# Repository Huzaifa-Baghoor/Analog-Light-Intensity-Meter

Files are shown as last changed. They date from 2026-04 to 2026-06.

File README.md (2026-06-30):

# Analog Light Intensity Meter

I wanted to make some projects without microcontroller so I made this **light intensity meter** which indicates light in 10 distinct levels.
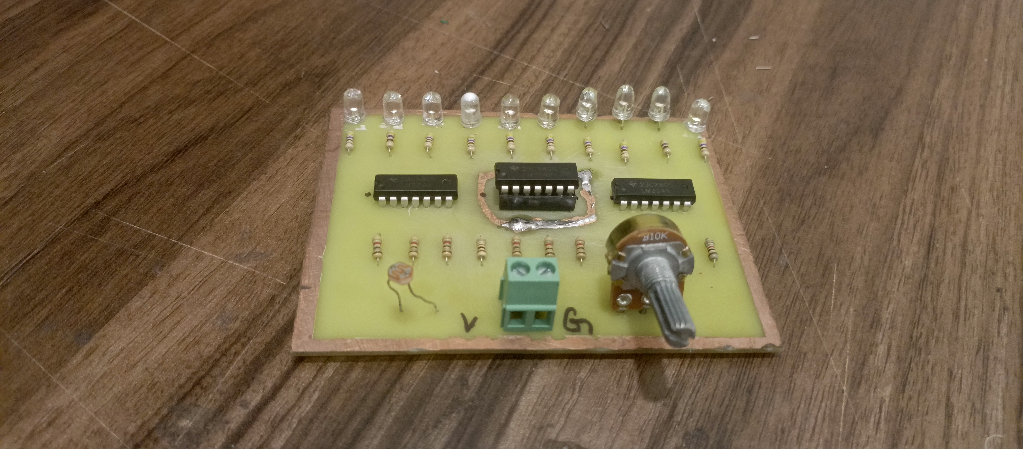
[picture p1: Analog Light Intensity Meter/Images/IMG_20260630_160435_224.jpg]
3D Model


## Working

The **LM324N IC** contains 4 OpAmps which are being used as Comparaters. They compare two voltages i.e. **reference voltage** and **signal voltage** and  if signal voltage is higher than reference voltage the output is on and all the LEDs till that level turn on.

## PCB and Connections

The Project is powered by a 9V source the thee +9V goes to the VCC of op Amps and top of the voltage divider bridge and top of the sensitivity control area the Gnd goes to the GND of op Amps and bottom of the voltage divider bridge and bottom of the sensitivity control area . The signal from the senstivity control area goes to the +ve of op amps and the 10 voltage levels are connected to -ve of 10 individual op Amps.

**The PCB isn't working but if you try to make it on breadboard using the same schematics then it works fine.**

|Schematics|Tracks|
| :---: | :---: |
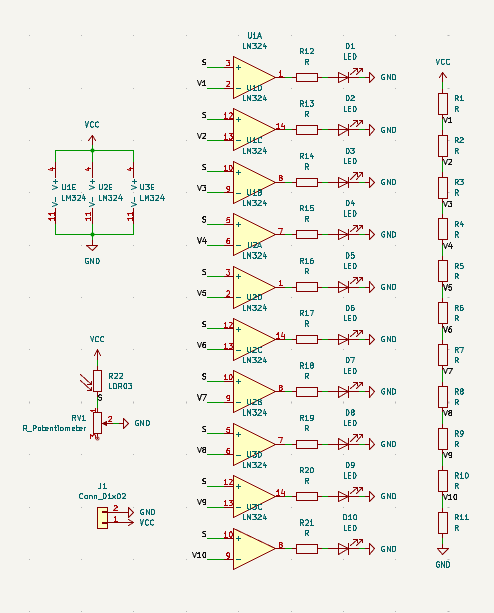
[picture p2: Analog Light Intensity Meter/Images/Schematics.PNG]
schemetics
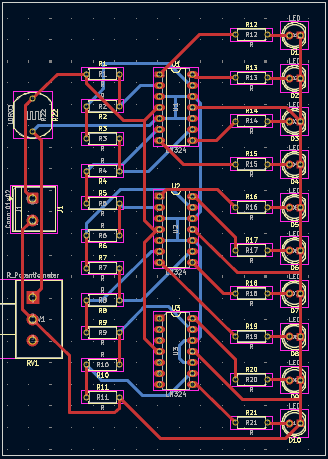
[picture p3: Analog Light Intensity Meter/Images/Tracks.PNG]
Tracks
|  |  |

## Bill of Materials (BOM)

| Name | Purpose | Quantity | Total Cost (USD) | Link | Distributor |
| :---: | :---: | :---: | :---: | :---: | :---: |
| LEDs | Indicator | 10 | 7 | [LED](https://www.aliexpress.com/item/1005003337390606.html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) | AliExpress |
| PCB | to assemble the project | 1 | 35 | [PCB](https://cart.jlcpcb.com/quote/gerberviewThree/?qs=edae4f3f128a488bbbc25f9c6c296d6c_1_0_1_0_0.html) | AliExpress
| IC Base | to solder ICs on PCB or Veroboard |  | 2 | [IC Base](https://www.aliexpress.com/item/32866483409.html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) | AliExpress |
| Potentiometer | Control Senstivity | 1 | 3 | [Potentiometer](https://www.aliexpress.com/item/1005007730415902.html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) | AliExpress |
| LDR | Detecting Light level | 1 | 3 | [LDR](https://www.aliexpress.com/item/1005010362917938.html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) | AliExpress |
| 1kΩ Resistor | For Voltage Divider Bridge | 11 | 2 | [1K Resistor](https://www.aliexpress.com/item/1005009177180559.html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) | AliExpress |
| 470Ω Resistor | for LEDs | 10 | 2 | [470R Resistor](https://www.aliexpress.com/item/1005009177180559.html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) | AliExpress |
| LM324N | Quad OpAmp ICs | 6 | 7 | [LM324N IC](https://www.aliexpress.com/item/1005008583669771.html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) | AliExpress |

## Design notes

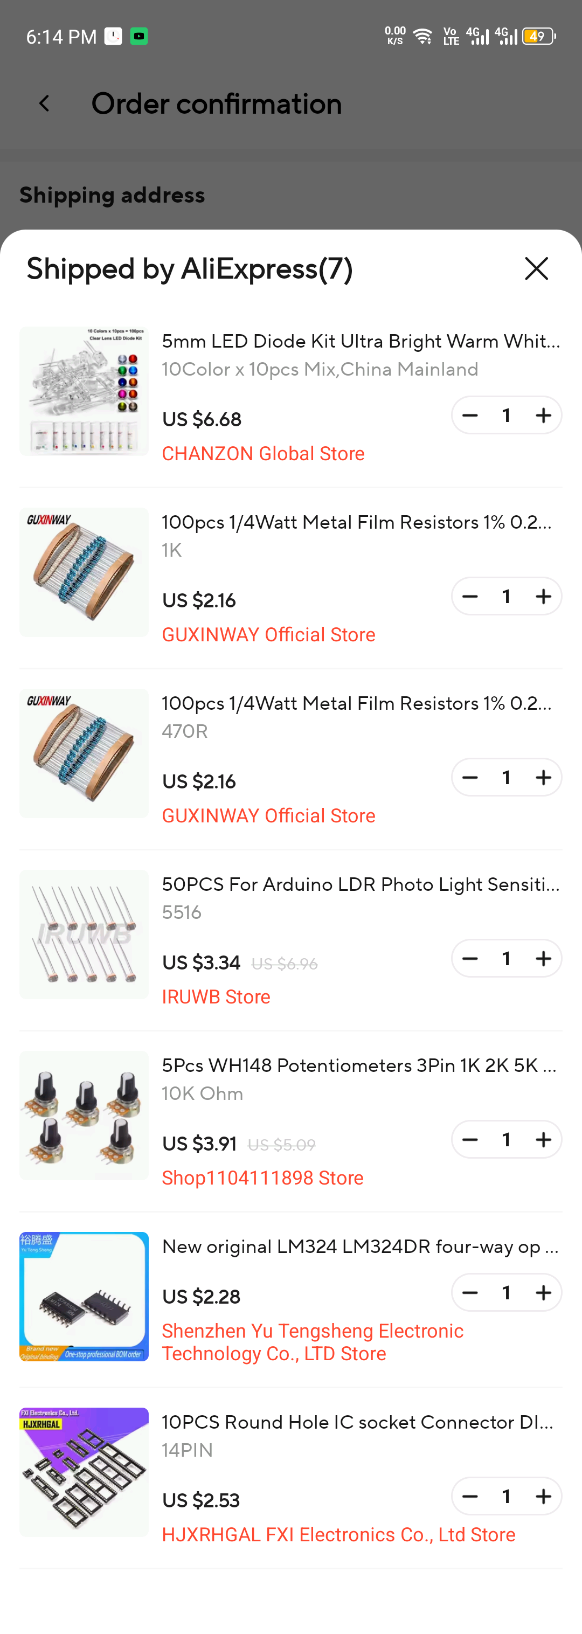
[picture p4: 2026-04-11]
Analog Light Intensity Meter/Images/Screenshot_20260411-181429.png

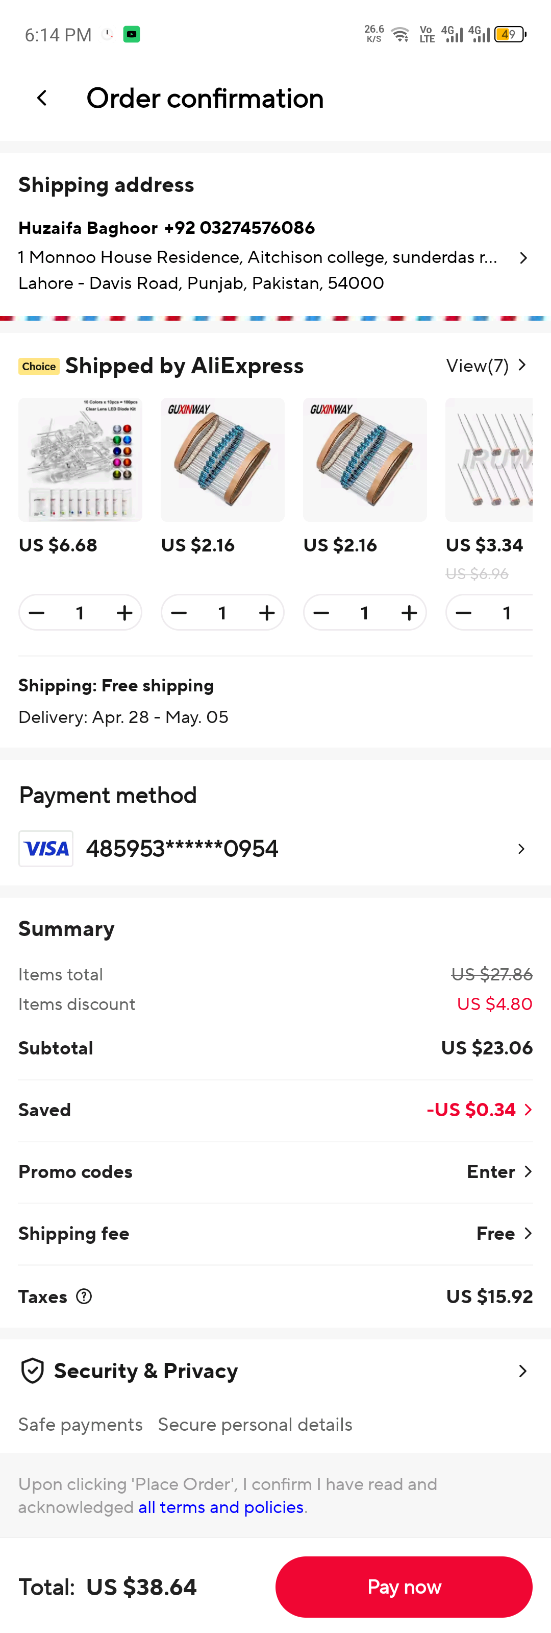
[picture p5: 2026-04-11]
Analog Light Intensity Meter/Images/Screenshot_20260411-181441.png

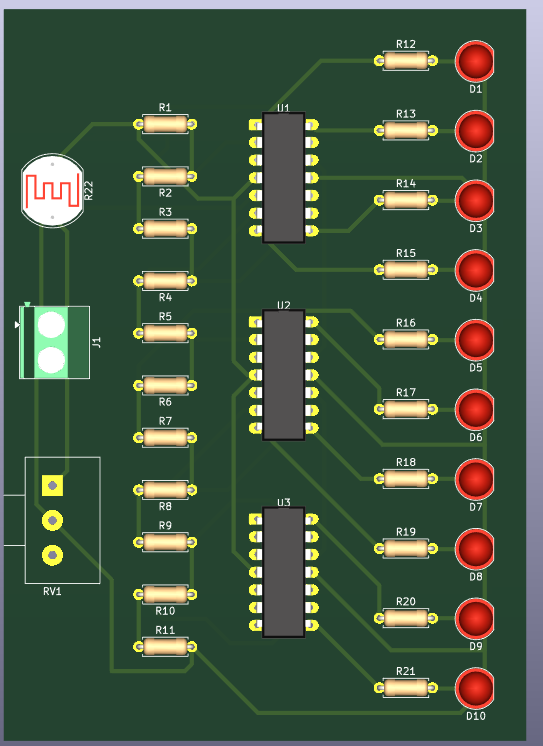
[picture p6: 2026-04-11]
Analog Light Intensity Meter/Images/3D.PNG

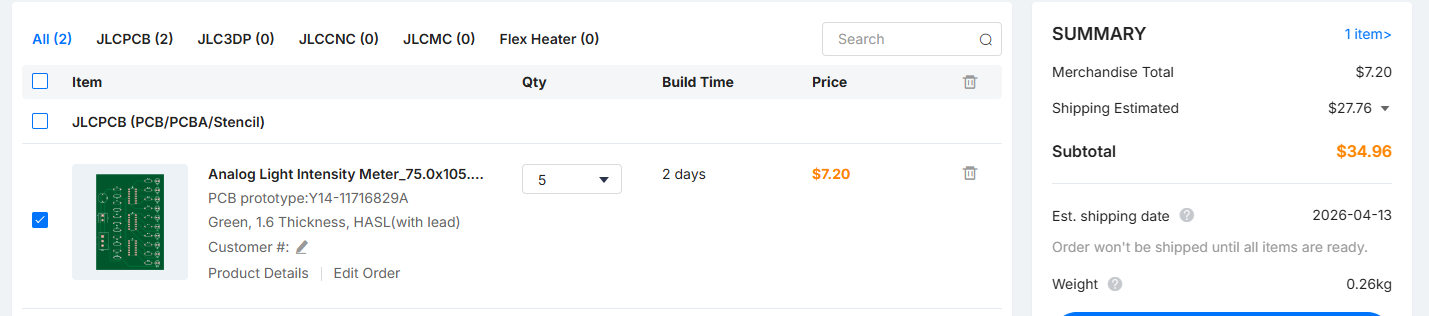
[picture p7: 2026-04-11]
Analog Light Intensity Meter/Images/JLCPCB.PNG

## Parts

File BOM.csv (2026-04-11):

Name | Purpose | Quantity | Total Cost (USD) | Link | Distributor
LEDs | Indicator | 10 | 7 | https://www.aliexpress.com/item/1005003337390606.html?mp=1 | AliExpress
PCB | to assemble the project | 1 | 35 | https://cart.jlcpcb.com/quote/gerberviewThree/?qs=edae4f3f128a488bbbc25f9c6c296d6c_1_0_1_0_0.html | AliExpress
IC Base | to solder ICs on PCB or Veroboard |  | 2 | https://www.aliexpress.com/item/32866483409.html?mp=1 | AliExpress
Potentiometer | Control Senstivity | 1 | 3 | https://www.aliexpress.com/item/1005007730415902.html?mp=1 | AliExpress
LDR | Detecting Light level | 1 | 3 | https://www.aliexpress.com/item/1005010362917938.html?mp=1 | AliExpress
1kΩ Resistor | For Voltage Divider Bridge | 11 | 2 | https://www.aliexpress.com/item/1005009177180559.html?mp=1 | AliExpress
470Ω Resistor | for LEDs | 10 | 2 | https://www.aliexpress.com/item/1005009177180559.html?mp=1 | AliExpress
LM324N | Quad OpAmp ICs | 6 | 7 | https://www.aliexpress.com/item/1005008583669771.html?mp=1 | AliExpress

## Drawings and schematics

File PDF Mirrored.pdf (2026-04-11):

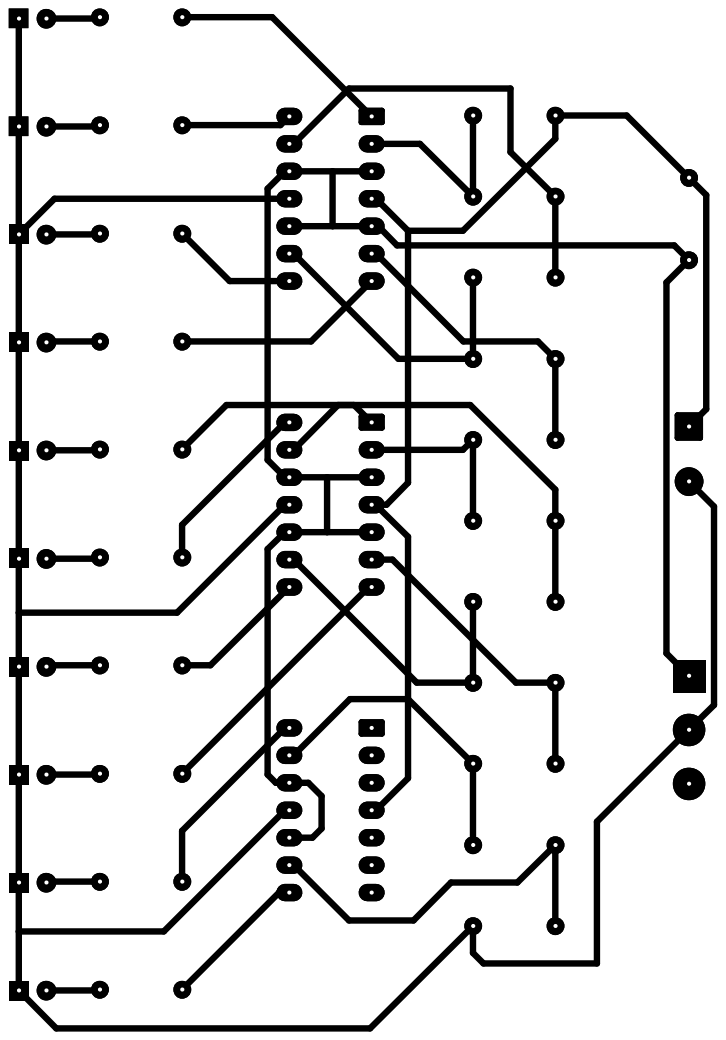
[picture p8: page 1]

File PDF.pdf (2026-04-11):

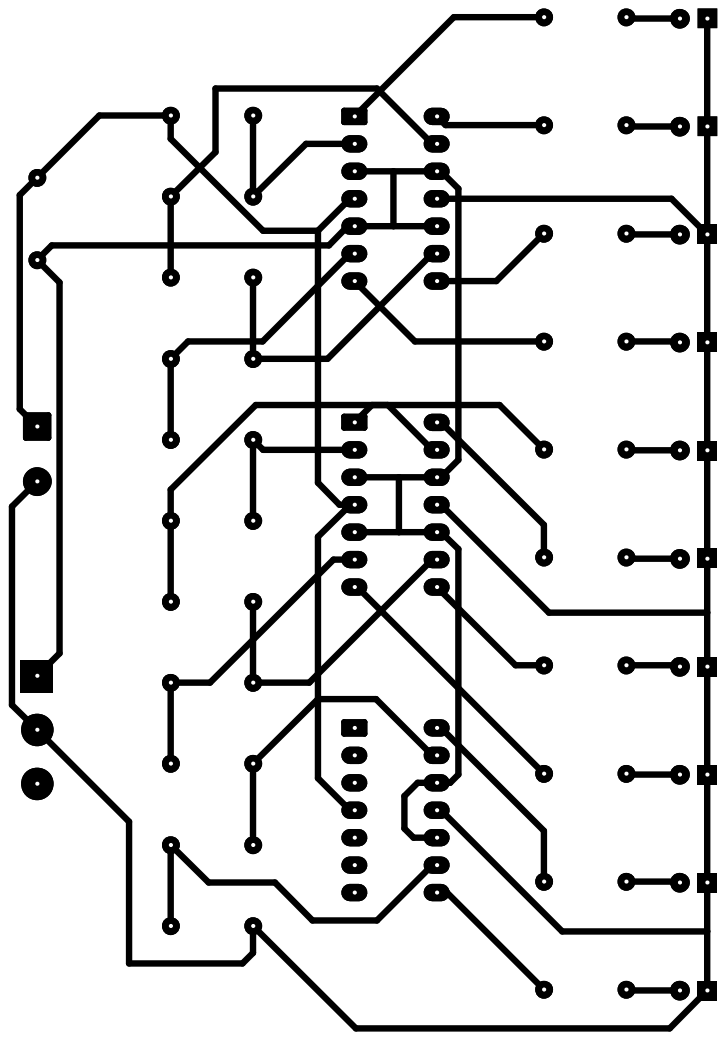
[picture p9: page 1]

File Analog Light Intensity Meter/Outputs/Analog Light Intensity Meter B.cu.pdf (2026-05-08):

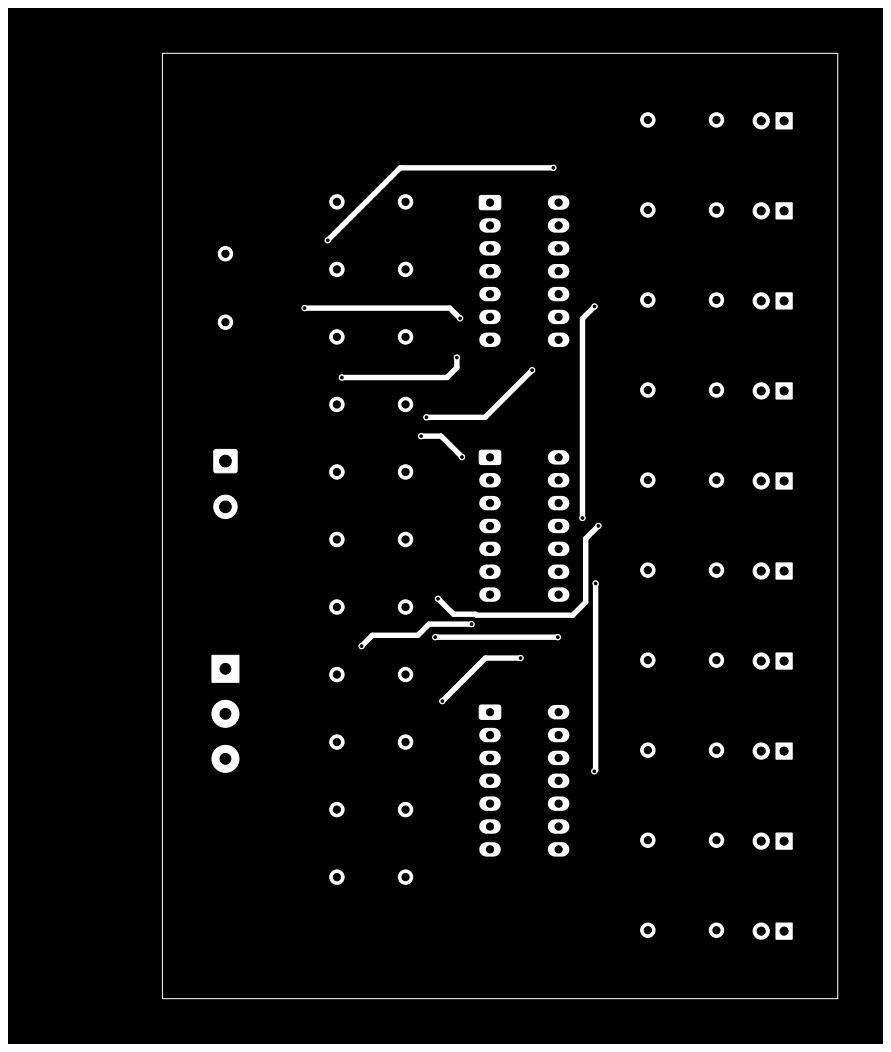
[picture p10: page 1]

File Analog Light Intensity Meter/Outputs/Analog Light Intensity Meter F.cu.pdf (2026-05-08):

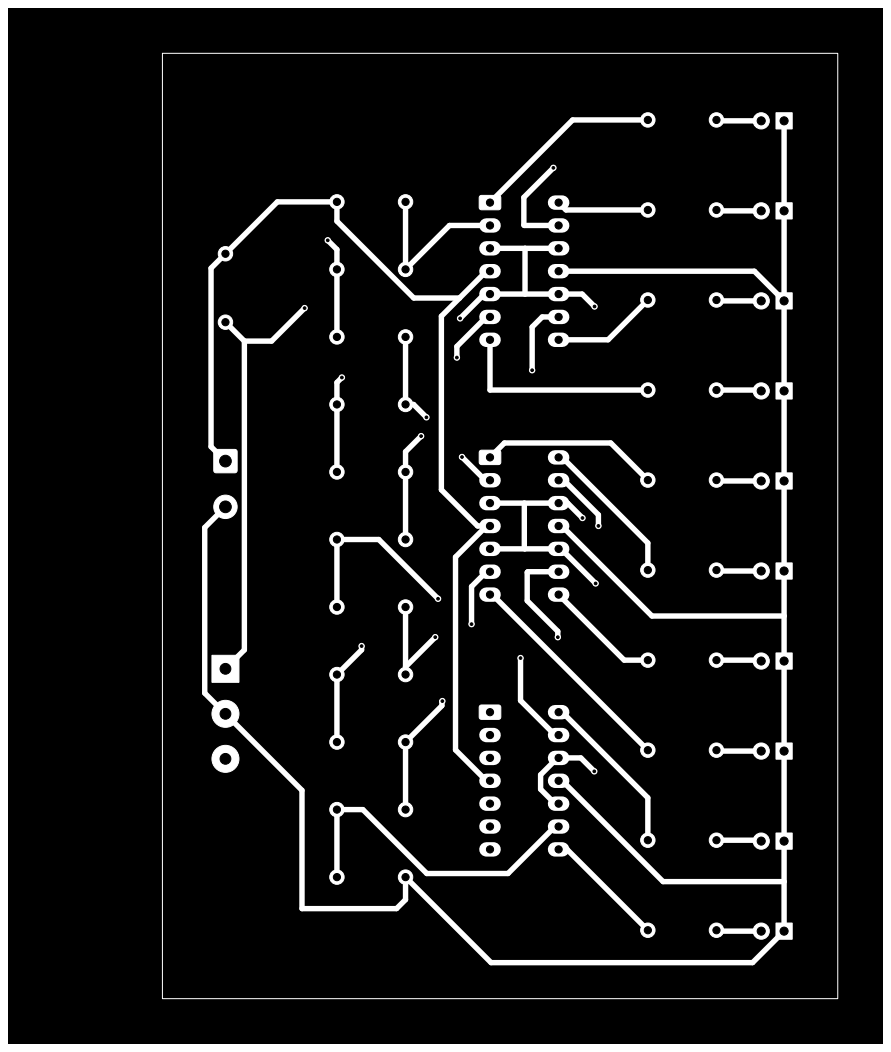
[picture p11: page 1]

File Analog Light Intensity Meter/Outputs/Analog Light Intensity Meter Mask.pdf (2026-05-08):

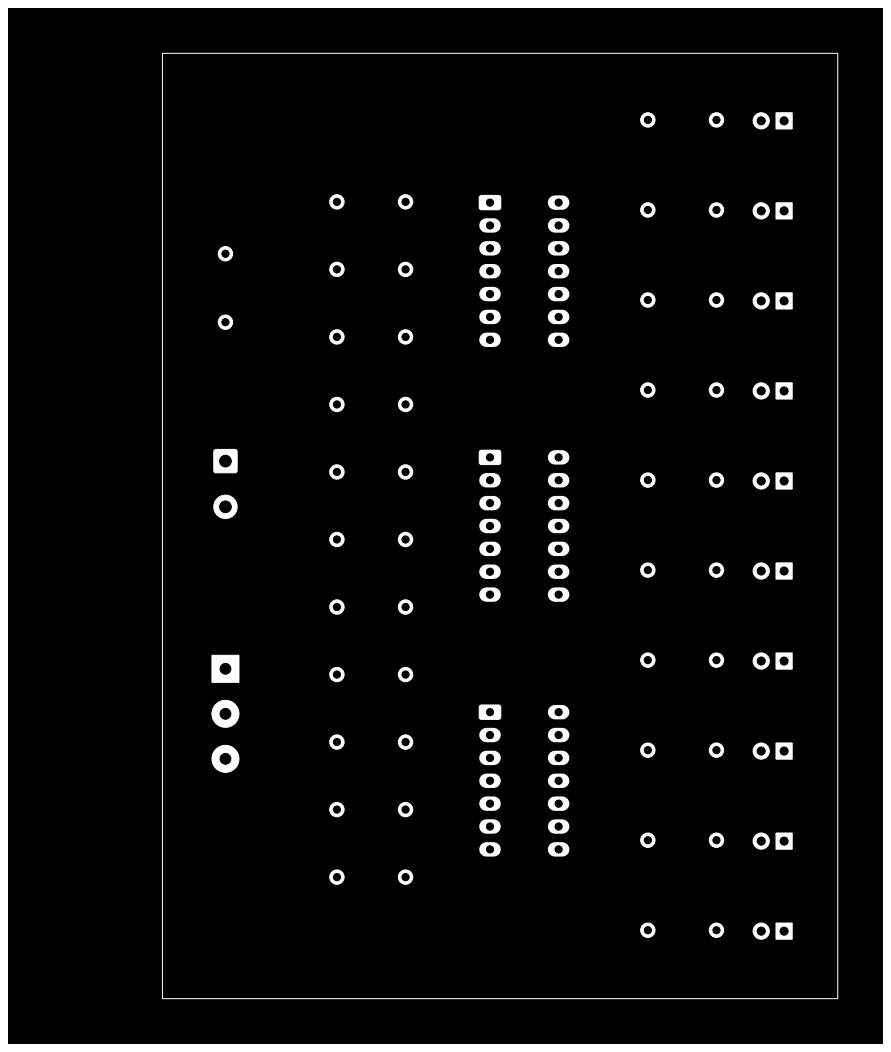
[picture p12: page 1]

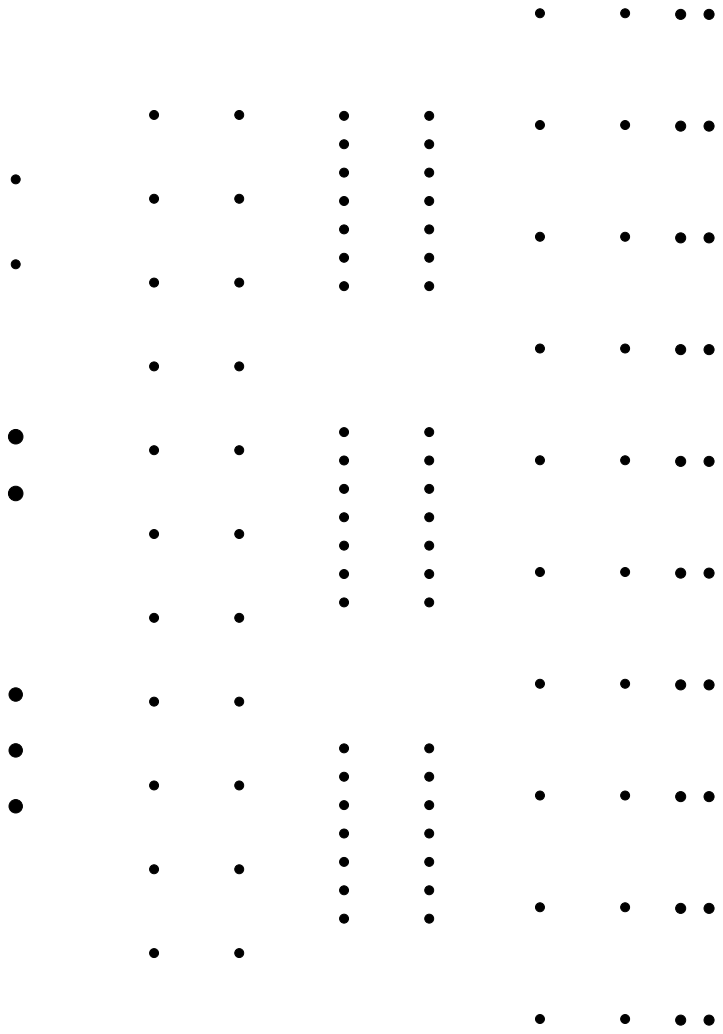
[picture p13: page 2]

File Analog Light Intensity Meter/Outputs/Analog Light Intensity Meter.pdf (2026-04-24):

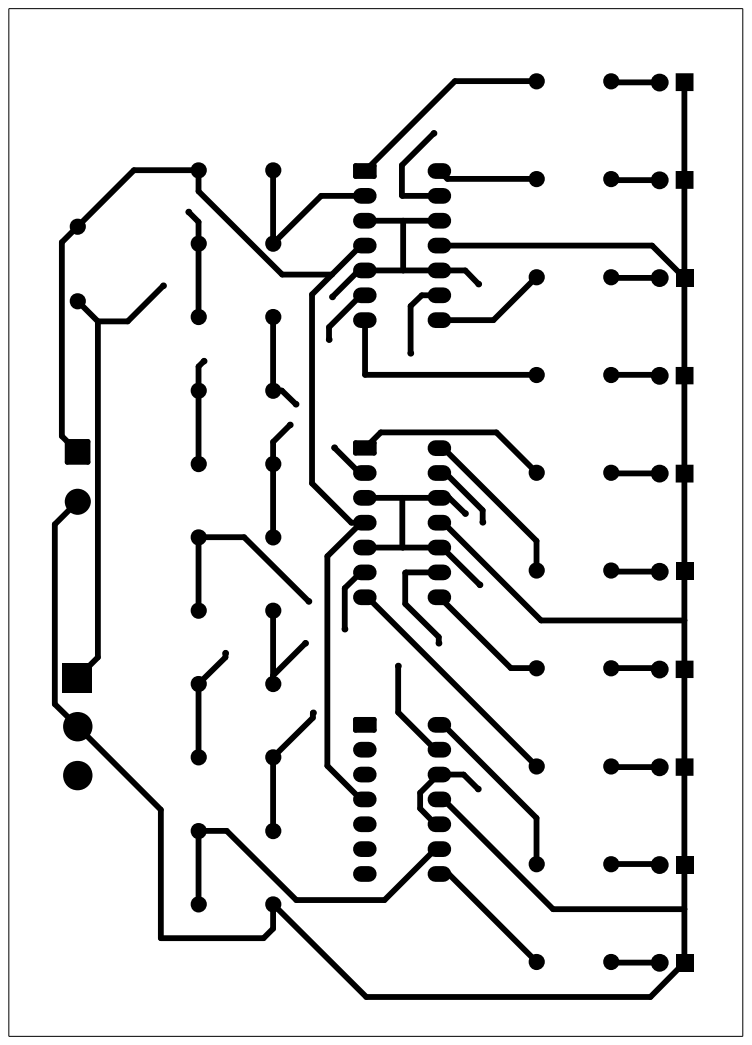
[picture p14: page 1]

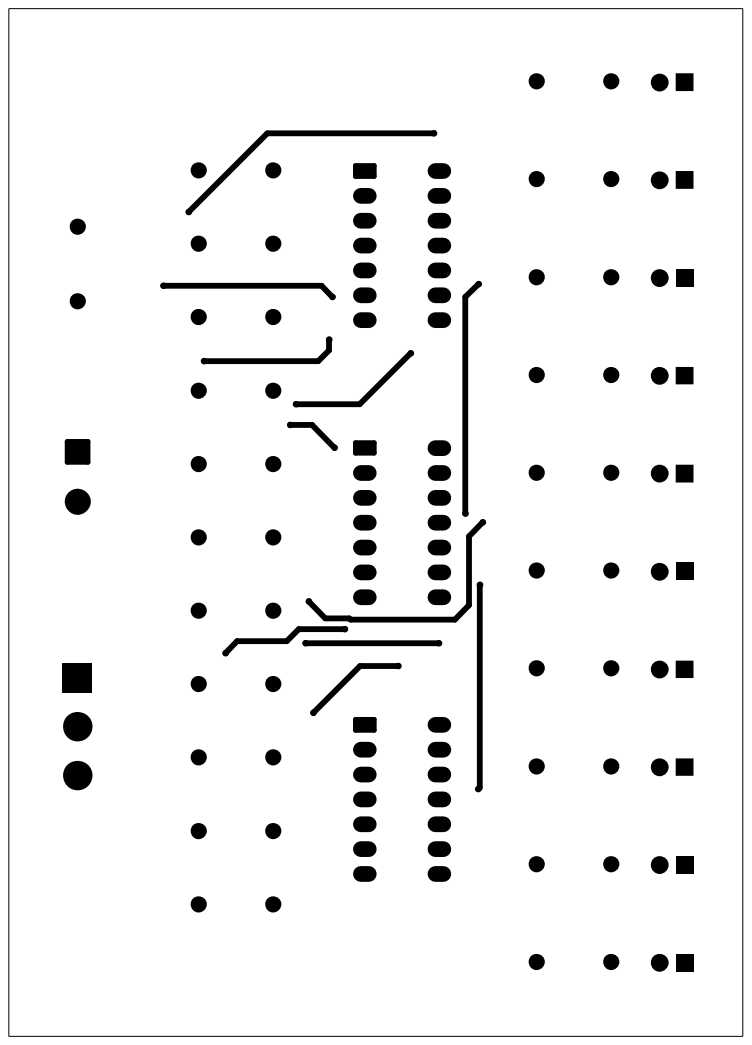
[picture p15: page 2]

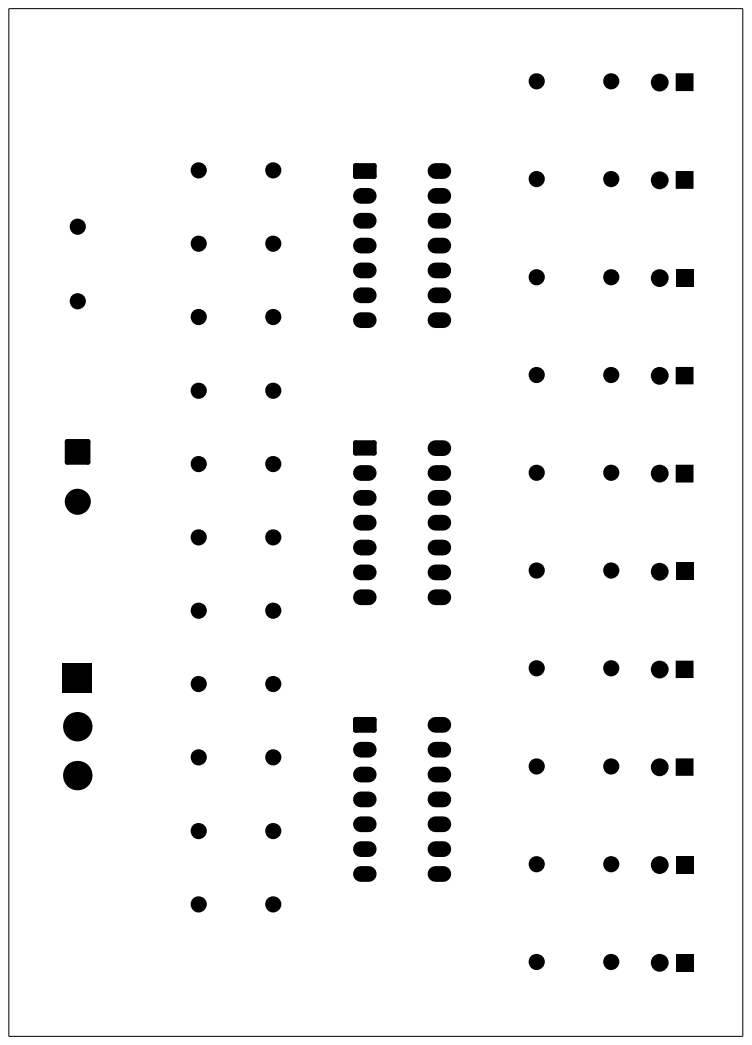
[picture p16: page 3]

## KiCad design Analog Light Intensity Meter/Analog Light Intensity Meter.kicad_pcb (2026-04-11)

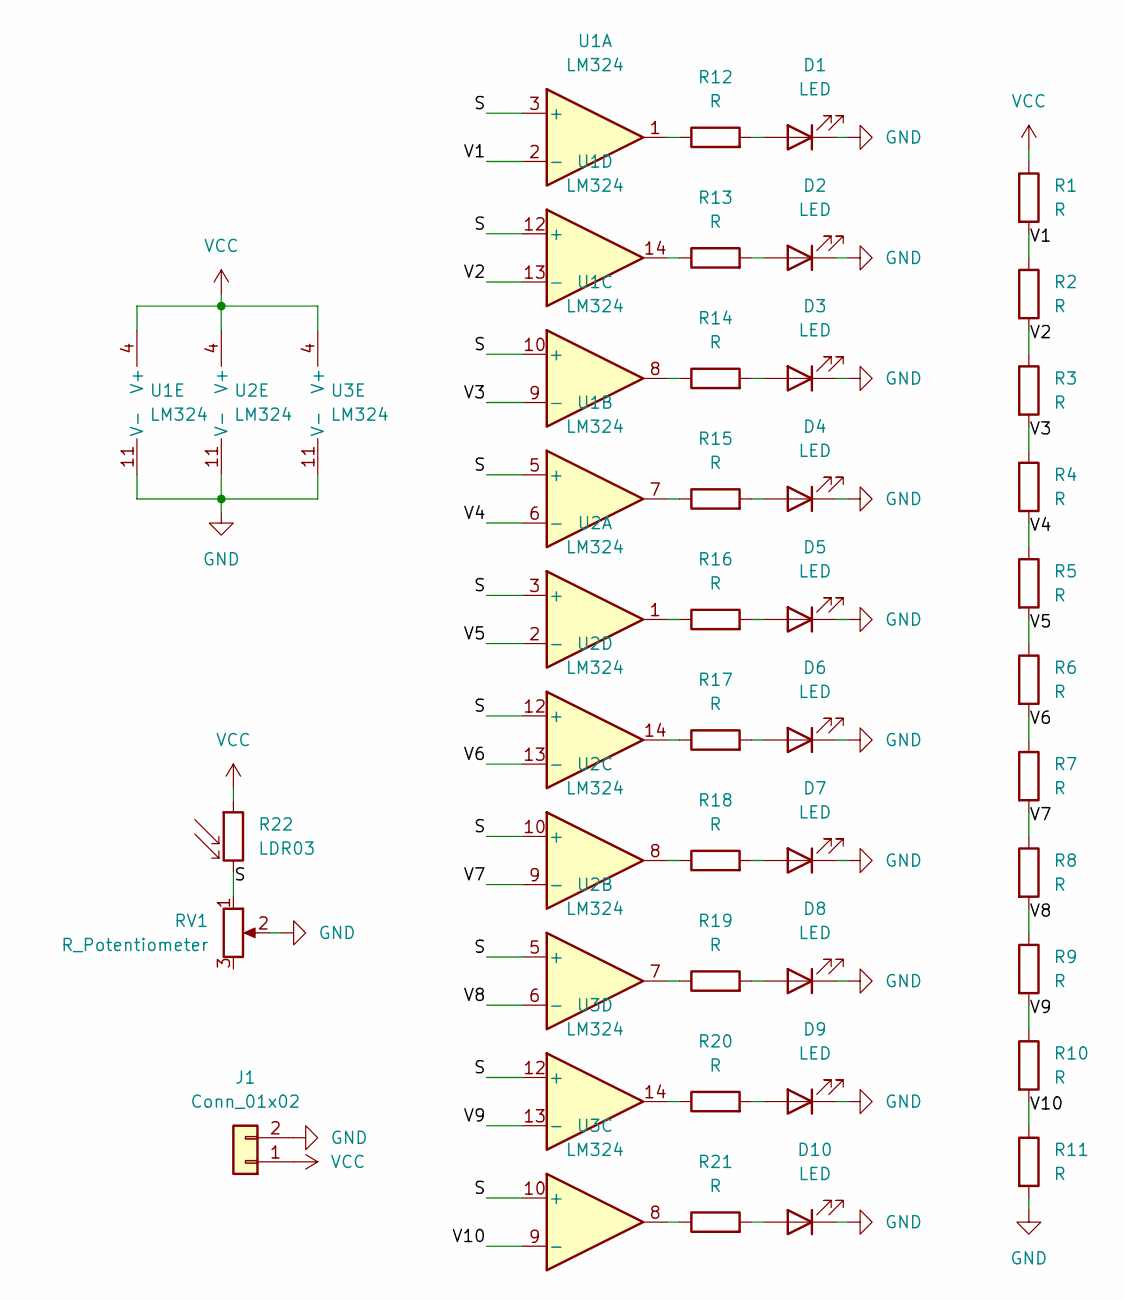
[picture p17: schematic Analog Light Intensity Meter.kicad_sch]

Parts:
D1, D2, D3, D4, D5, D6, D7, D8, D9, D10: LED; LED_D5.0mm
J1: Conn_01x02; TerminalBlock_Phoenix_MKDS-1,5-2-5.08_1x02_P5.08mm_Horizont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
R1, R2, R3, R4, R5, R6, R7, R8, R9, R10, R11, R12, R13, R14, R15, R16, R17, R18, R19, R20, R21: R; R_Axial_DIN0207_L6.3mm_D2.5mm_P7.62mm_Horizontal
R22: LDR03; R_LDR_10x8.5mm_P7.6mm_Vertical
RV1: R_Potentiometer; Potentiometer_Alps_RK163_Single_Horizontal
U1, U2: LM324; DIP-14_W7.62mm_LongPads
U3: LM324

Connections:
/S: R22.2, RV1.1, U1.3 (+), U1.5 (+), U1.10 (+), U1.12 (+), U2.3 (+), U2.5 (+), U2.10 (+), U2.12 (+), U3.10 (+), U3.12 (+)
/V1: R1.2, R2.1, U1.2 (-)
/V2: R2.2, R3.1, U1.13 (-)
/V3: R3.2, R4.1, U1.9 (-)
/V4: R4.2, R5.1, U1.6 (-)
/V5: R5.2, R6.1, U2.2 (-)
/V6: R6.2, R7.1, U2.13 (-)
/V7: R7.2, R8.1, U2.9 (-)
/V8: R8.2, R9.1, U2.6 (-)
/V9: R9.2, R10.1, U3.13 (-)
/V10: R10.2, R11.1, U3.9 (-)
GND: D1.1 (K), D2.1 (K), D3.1 (K), D4.1 (K), D5.1 (K), D6.1 (K), D7.1 (K), D8.1 (K), D9.1 (K), D10.1 (K), J1.2, R11.2, RV1.2, U1.11 (V-), U2.11 (V-), U3.11 (V-)
unnamed: D1.2 (A), R12.2
unnamed: D2.2 (A), R13.2
unnamed: D3.2 (A), R14.2
unnamed: D4.2 (A), R15.2
unnamed: D5.2 (A), R16.2
unnamed: D6.2 (A), R17.2
unnamed: D7.2 (A), R18.2
unnamed: D8.2 (A), R19.2
unnamed: D9.2 (A), R20.2
unnamed: D10.2 (A), R21.2
unnamed: R12.1, U1.1
unnamed: R13.1, U1.14
unnamed: R14.1, U1.8
unnamed: R15.1, U1.7
unnamed: R16.1, U2.1
unnamed: R17.1, U2.14
unnamed: R18.1, U2.8
unnamed: R19.1, U2.7
unnamed: R20.1, U3.14
unnamed: R21.1, U3.8
VCC: J1.1, R1.1, R22.1, U1.4 (V+), U2.4 (V+), U3.4 (V+)

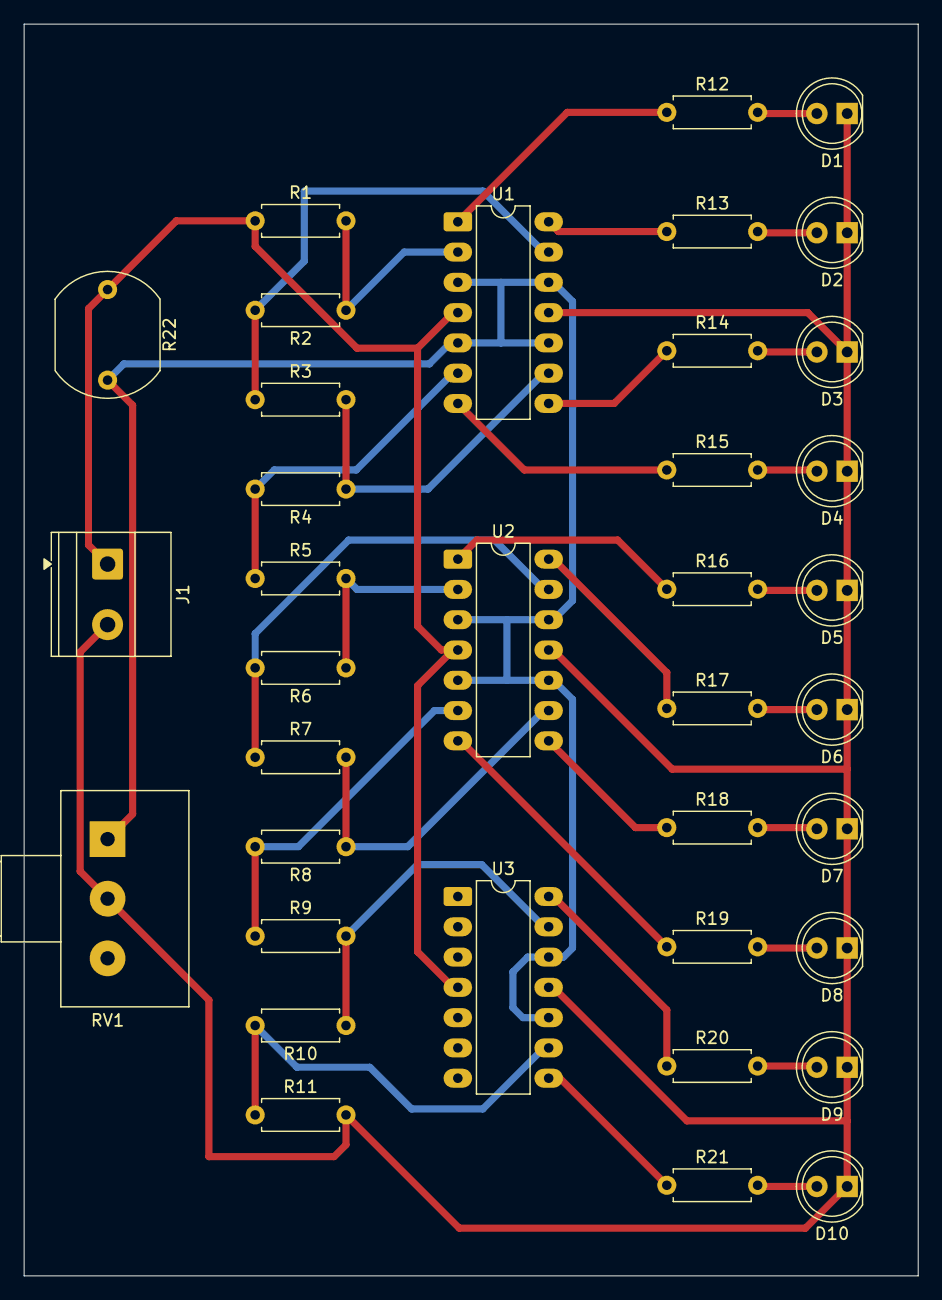
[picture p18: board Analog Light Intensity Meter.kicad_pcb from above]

Board: 2 copper layers, 75.0 x 105.0 mm, 37 parts (0 on the bottom side), 33 nets.
